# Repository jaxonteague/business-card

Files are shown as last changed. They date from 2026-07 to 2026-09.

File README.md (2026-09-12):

# Business Card - Floppy Bird

<p align="center">
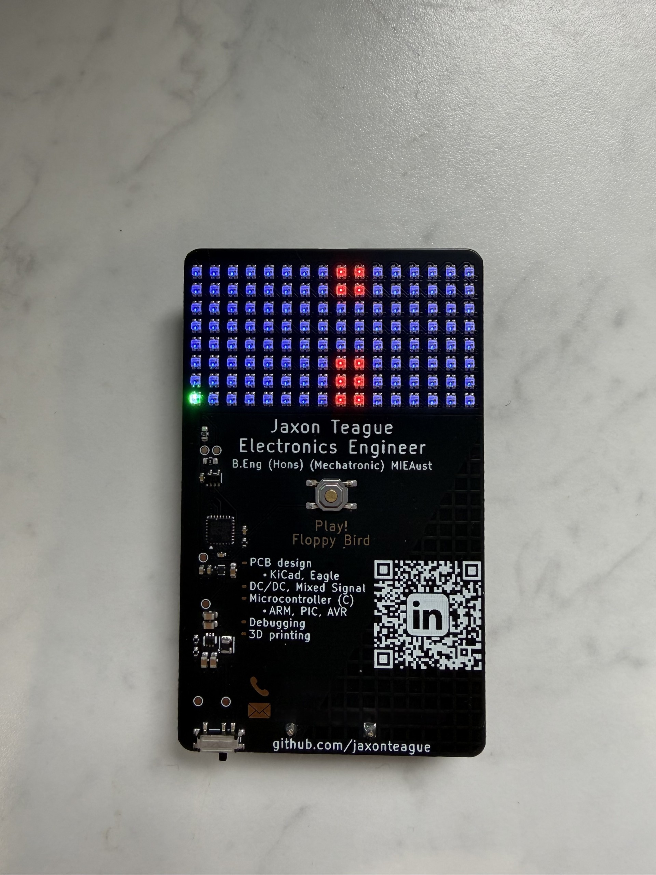
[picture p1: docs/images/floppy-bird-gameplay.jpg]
Floppy Bird running on the LED business card
  
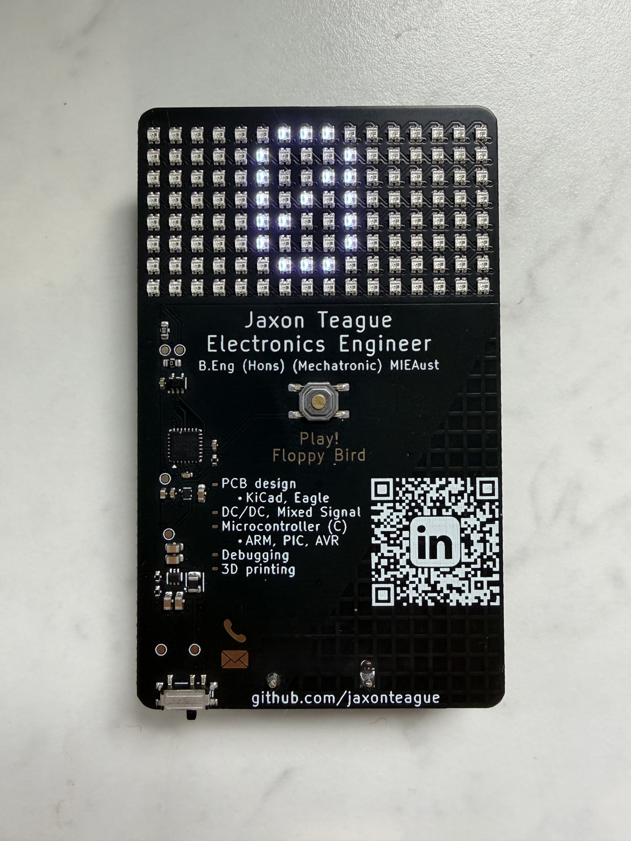
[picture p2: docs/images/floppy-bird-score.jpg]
Score displayed on the LED business card
  
</p>

I wanted my business card to do more than sit in someone's wallet, so I built
one with a custom PCB, 128 RGB LEDs, and a playable game called **Floppy Bird**.
It brings together PCB design, embedded C, real-time game logic, all displayed on
a 16x8 custom led mattrix display.

## What it does

Floppy Bird is controlled with a single physical button. Pressing it makes the
bird flap while two-pixel-wide pipes move across the display. Passing a pipe
earns a point, and the game gradually speeds up across ten difficulty levels.

The player gets three lives. Once all three lives are gone, the final score
appears.

## What I built

- A custom KiCad schematic and PCB for an STM32C031 and 8x16 addressable RGB
  LED matrix.
- A framebuffer-based LED driver that converts RGB values into WS2812 data and
  sends each frame using SPI with DMA.
- Non-blocking game logic covering bird physics, random pipe gaps, collisions,
  lives, scoring, difficulty progression, and game-over handling.
- Interrupt-driven button input with the actual game update kept in the main
  loop, keeping the interrupt handler short.
- Low-power idle time using the Cortex-M0+ wait-for-interrupt instruction.
- Production files including Gerbers, a bill of materials, and component
  placement data.

## Hardware

At the centre of the card is an STM32C031, a small Cortex-M0+ microcontroller
that handles the game, button input, and LED data. The display is made from 128
individually addressable RGB LEDs arranged as 16 columns by 8 rows. A single
physical button provides the game input, keeping the interface simple and making
the card immediately playable.

The card is powered by two AAA batteries. A boost converter raises the battery
voltage to 5 V for the LED matrix, while an LDO steps that rail down to 3.3 V for
the microcontroller. Because the STM32 and LEDs operate at different logic
levels, a level converter shifts the 3.3 V SPI data signal up to 5 V before it
reaches the LEDs. The button input is debounced in hardware with an RC filter so
a single press produces a clean, reliable transition.

The LEDs share one serial data chain and are updated from an SPI peripheral using
DMA. This lets the microcontroller transfer a complete frame in the background
instead of spending all of its time manually generating the LED waveform.

Power consumption was an important part of the design because 128 RGB LEDs can
draw a lot of current at full output. The firmware keeps brightness deliberately
low, and the hardware includes local decoupling for the LED supply.

While the led matrix is cool, it is quite power hungry. Drawing 3/4W, the display
will run for 4-6 hours from 2x AAA batteries.

PCB is 2 layer double sided. The matrix is connected in alternate directions so
as to simpliy routing and avoid unnecessary trace lengths.

## A few interesting details

The LEDs are routed in a serpentine pattern on the PCB. The driver translates
normal `(x, y)` coordinates into the physical LED order, so the game code does
not need to know how the traces are laid out.

The bird uses fixed-point physics instead of floating point. This makes its
movement smoother than jumping directly between the eight rows while staying
lightweight for the Cortex-M0+ microcontroller. Fractional accumulators give
fine control over gravity and pipe speed without floating-point overhead.

The firmware is split into small modules: game logic and rendering are separate
from the LED driver, and adjustable gameplay values live in one configuration
header.

The leds are very bright, so to same battery and eyesight, they are set to very
low brightness.

## Tools and technologies

- Embedded C
- STM32C031 microcontroller
- STM32CubeMX and STM32CubeIDE
- GPIO interrupts, SPI, DMA, and low-power operation
- WS2812-compatible RGB LEDs
- Fixed-point arithmetic and real-time state machines
- KiCad schematic capture and PCB layout
- Design-for-manufacture files for JLCPCB

## Repository contents

The `pcb` folder contains the KiCad design and manufacturing files. The STM32
firmware is in `microcontroller/business card`.

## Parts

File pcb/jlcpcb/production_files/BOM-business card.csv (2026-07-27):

Comment | Designator | Footprint | LCSC | Quantity
0R | R6 | R_0603_1608Metric | C21189 | 1
100 | R1 | R_0603_1608Metric | C22775 | 1
100k | R4,R5 | R_0402_1005Metric | C25741 | 2
100nF | C10,C100,C101,C102,C103,C104,C105,C106,C107,C108,C109,C11,C110,C111,C112,C113,C114,C115,C116,C117,C118,C119,C12,C120,C121,C122,C123,C124,C125,C126,C127,C128,C129,C13,C130,C131,C132,C133,C134,C135,C136,C137,C138,C14,C15,C16,C17,C18,C19,C20,C21,C22,C23,C24,C25,C26,C27,C28,C29,C30,C31,C32,C33,C34,C35,C36,C37,C38,C39,C40,C41,C42,C43,C44,C45,C46,C47,C48,C49,C50,C51,C52,C53,C54,C55,C56,C57,C58,C59,C6,C60,C61,C62,C63,C64,C65,C66,C67,C68,C69,C70,C71,C72,C73,C74,C75,C76,C77,C78,C79,C8,C80,C81,C82,C83,C84,C85,C86,C87,C88,C89,C9,C90,C91,C92,C93,C94,C95,C96,C97,C98,C99 | C_0402_1005Metric | C1525 | 132
10uF | C7 | C_0402_1005Metric | C15525 | 1
10uF | C1,C2,C3,C4 | C_0603_1608Metric | C96446 | 4
2.2uF | C5 | C_0603_1608Metric | C23630 | 1
470nH | L1 | L_Coilcraft_0805HQ_2012Metric | C337914 | 1
732k | R3 | R_0402_1005Metric | C409928 | 1
74AHCT1G125 | U4 | SOT-353_SC-70-5 | C7039245 | 1
Battery | BT1 | BatteryHolder_Keystone_2468_2xAAA | C254917 | 1
STM32C031G6Ux | U1 | QFN-28_4x4mm_P0.5mm | C7324966 | 1
SW_SPDT | SW1 | SW_SPDT_PCM12 | C221841 | 1
TLV71333PDBV | U3 | Texas_X2SON-4_1x1mm_P0.65mm | C90840 | 1
TPS61023DRLR | U2 | DRL0006A | C919459 | 1
Tactile Button, 160gf | S1 | SW-SMD_4P-L5.1-W5.1-P3.70-LS6.5-TL-2 | C318884 | 1
WS2812B | D1,D10,D100,D101,D102,D103,D104,D105,D106,D107,D108,D109,D11,D110,D111,D112,D113,D114,D115,D116,D117,D118,D119,D12,D120,D121,D122,D123,D124,D125,D126,D127,D128,D13,D14,D15,D16,D17,D18,D19,D2,D20,D21,D22,D23,D24,D25,D26,D27,D28,D29,D3,D30,D31,D32,D33,D34,D35,D36,D37,D38,D39,D4,D40,D41,D42,D43,D44,D45,D46,D47,D48,D49,D5,D50,D51,D52,D53,D54,D55,D56,D57,D58,D59,D6,D60,D61,D62,D63,D64,D65,D66,D67,D68,D69,D7,D70,D71,D72,D73,D74,D75,D76,D77,D78,D79,D8,D80,D81,D82,D83,D84,D85,D86,D87,D88,D89,D9,D90,D91,D92,D93,D94,D95,D96,D97,D98,D99 | LED-SMD_4P-L1.6-W1.5_XL-1615RGBC-WS2812B | C5349954 | 128
TestPoint_Probe | TP5 | TestPoint_Pad_D1.0mm |  | 1
TestPoint_Probe | TP2 | TestPoint_Pad_D1.0mm |  | 1
TestPoint_Probe | TP1 | TestPoint_Pad_D1.0mm |  | 1
TestPoint_Probe | TP3 | TestPoint_Pad_D1.0mm |  | 1
TestPoint_Probe | TP4 | TestPoint_Pad_D1.0mm |  | 1
TestPoint_Probe | TP6 | TestPoint_Pad_D1.0mm |  | 1
Conn_ST_STDC14 | J1 | PinHeader_2x07_P1.27mm_Vertical_SMD |  | 1

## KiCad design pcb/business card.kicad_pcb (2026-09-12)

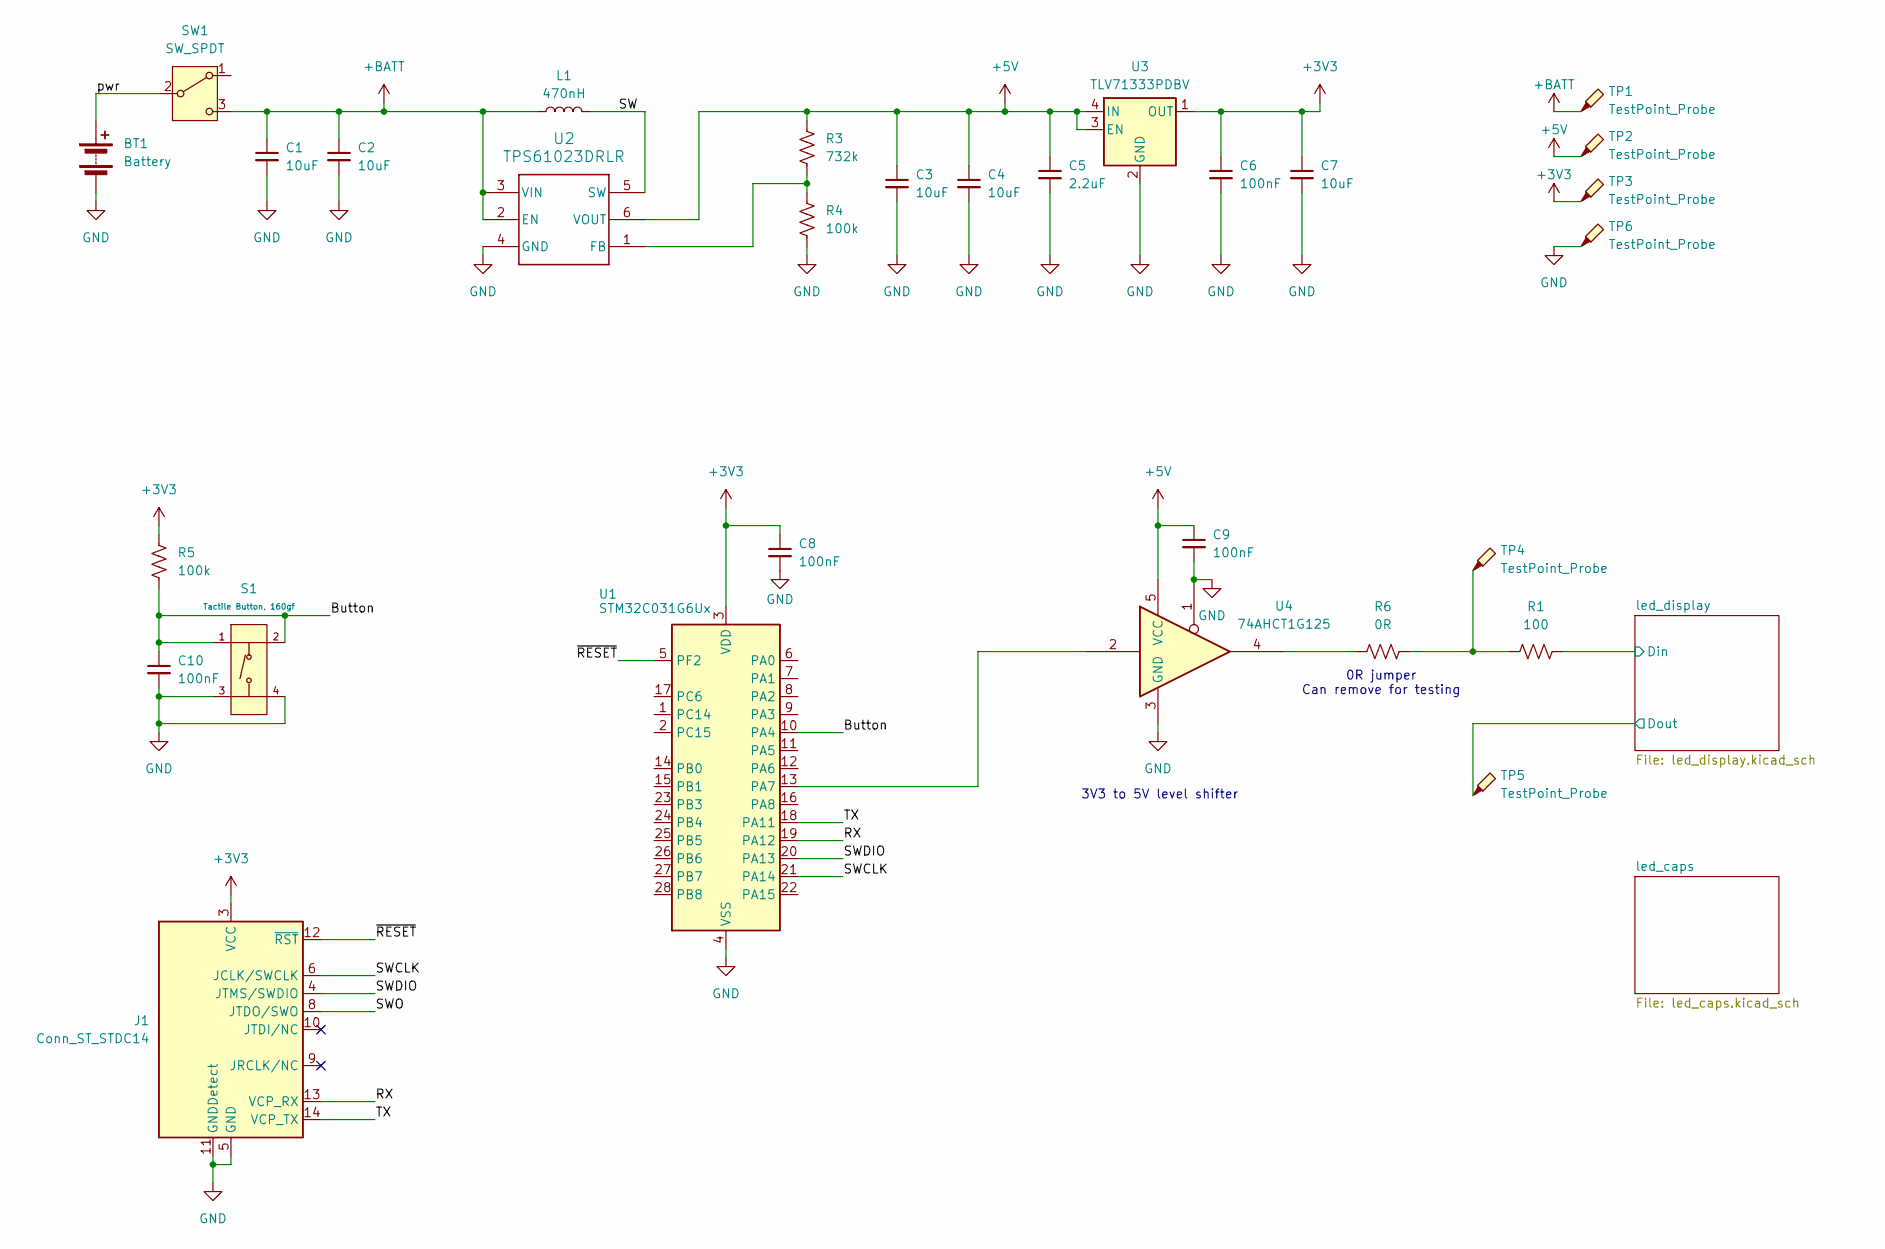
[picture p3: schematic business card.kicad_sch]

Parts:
BT1: Battery; BatteryHolder_Keystone_2468_2xAAA; LCSC C254917
C1, C2, C3, C4: 10uF; C_0603_1608Metric; LCSC C96446
C5: 2.2uF; C_0603_1608Metric; LCSC C23630
C6, C8, C9, C10: 100nF; C_0402_1005Metric; LCSC C1525
C7: 10uF; C_0402_1005Metric; LCSC C15525
J1: Conn_ST_STDC14; PinHeader_2x07_P1.27mm_Vertical_SMD; LCSC C41397116
L1: 470nH; L_Coilcraft_0805HQ_2012Metric; LCSC C337914
R1: 100; R_0603_1608Metric; LCSC C22775
R3: 732k; R_0402_1005Metric; LCSC C409928
R4, R5: 100k; R_0402_1005Metric; LCSC C25741
R6: 0R; R_0603_1608Metric; LCSC C21189
S1: Tactile Button, 160gf; SW-SMD_4P-L5.1-W5.1-P3.70-LS6.5-TL-2; Voltage Rating (Dc) 12V; Part TS-1187A-B-A-B; LCSC C318884
SW1: SW_SPDT; SW_SPDT_PCM12; LCSC C221841
TP1, TP2, TP3, TP4, TP5, TP6: TestPoint_Probe; TestPoint_Pad_D1.0mm
U1: STM32C031G6Ux; QFN-28_4x4mm_P0.5mm; LCSC C7324966
U2: TPS61023DRLR; DRL0006A; LCSC C919459
U3: TLV71333PDBV; Texas_X2SON-4_1x1mm_P0.65mm; LCSC C2867340
U4: 74AHCT1G125; SOT-353_SC-70-5; LCSC C7039245

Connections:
+3V3: C6.1, C7.1, C8.1, J1.3 (VCC), R5.1, TP3.1 (1_1), U1.3 (VDD), U3.1 (OUT)
+5V: C3.1, C4.1, C5.1, C9.1, R3.1, TP2.1 (1_1), U2.6 (VOUT), U3.3 (EN), U3.4 (IN), U4.5 (VCC); also elsewhere on the board
+BATT: C1.1, C2.1, L1.1, SW1.3 (C), TP1.1 (1_1), U2.2 (EN), U2.3 (VIN)
/Button: C10.1, R5.2, S1.1 (A), S1.2 (B), U1.10 (PA4)
/RX: J1.13 (VCP_RX), U1.19 (PA12)
/SW: L1.2, U2.5 (SW)
/SWCLK: J1.6 (JCLK/SWCLK), U1.21 (PA14)
/SWDIO: J1.4 (JTMS/SWDIO), U1.20 (PA13)
/SWO: J1.8 (JTDO/SWO)
/TX: J1.14 (VCP_TX), U1.18 (PA11)
/led_display/Din: R1.2; also elsewhere on the board
/led_display/Dout: TP5.1 (1_1); also elsewhere on the board
/pwr: BT1.1 (+), SW1.2 (B)
/~RESET: J1.12 (~RST), U1.5 (PF2)
GND: BT1.2 (-), C1.2, C2.2, C3.2, C4.2, C5.2, C6.2, C7.2, C8.2, C9.2, C10.2, J1.5 (GND), J1.7 (GND), J1.11 (GNDDetect), R4.2, S1.3 (C), S1.4 (D), TP6.1 (1_1), U1.4 (VSS), U2.4 (GND), U3.2 (GND), U4.1, U4.3 (GND); also elsewhere on the board
unnamed: R1.1, R6.2, TP4.1 (1_1)
unnamed: R6.1, U4.4
unnamed: U1.13 (PA7), U4.2
unnamed: R3.2, R4.1, U2.1 (FB)

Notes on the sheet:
0R jumper Can remove for testing
3V3 to 5V level shifter

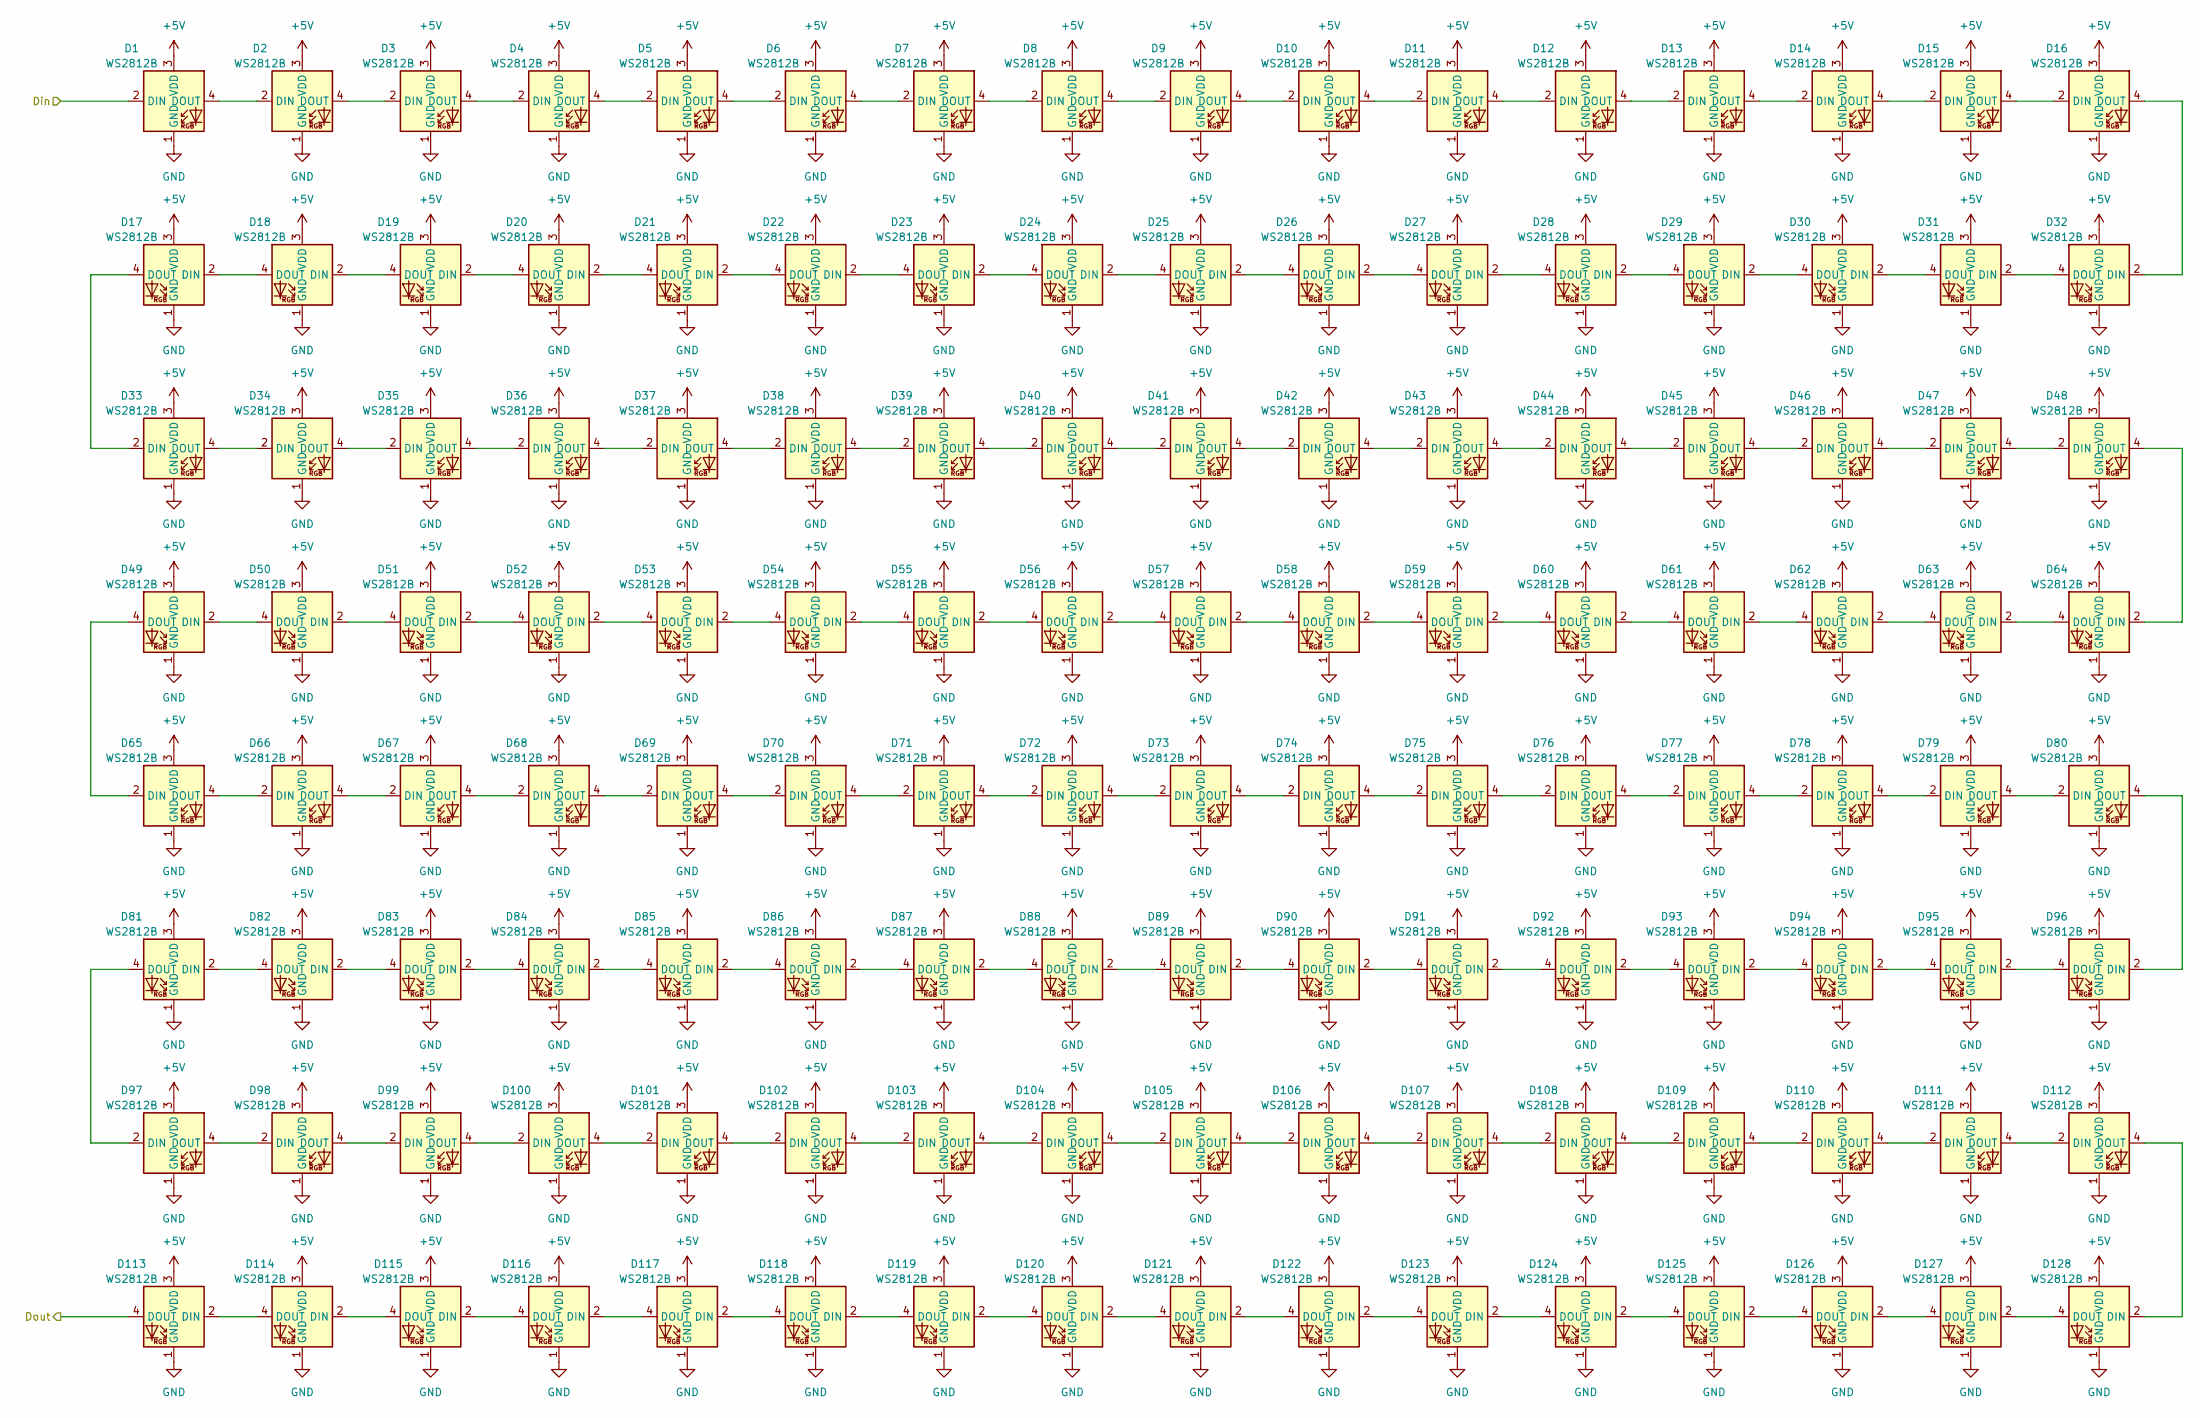
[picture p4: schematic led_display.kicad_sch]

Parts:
D1, D2, D3, D4, D5, D6, D7, D8, D9, D10, D11, D12, D13, D14, D15, D16, D17, D18, D19, D20, D21, D22, D23, D24, D25, D26, D27, D28, D29, D30, D31, D32, D33, D34, D35, D36, D37, D38, D39, D40, D41, D42, D43, D44, D45, D46, D47, D48, D49, D50, D51, D52, D53, D54, D55, D56, D57, D58, D59, D60, D61, D62, D63, D64, D65, D66, D67, D68, D69, D70, D71, D72, D73, D74, D75, D76, D77, D78, D79, D80, D81, D82, D83, D84, D85, D86, D87, D88, D89, D90, D91, D92, D93, D94, D95, D96, D97, D98, D99, D100, D101, D102, D103, D104, D105, D106, D107, D108, D109, D110, D111, D112, D113, D114, D115, D116, D117, D118, D119, D120, D121, D122, D123, D124, D125, D126, D127, D128: WS2812B; LED-SMD_4P-L1.6-W1.5_XL-1615RGBC-WS2812B; LCSC C5349954

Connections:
+5V: D1.3 (VDD), D2.3 (VDD), D3.3 (VDD), D4.3 (VDD), D5.3 (VDD), D6.3 (VDD), D7.3 (VDD), D8.3 (VDD), D9.3 (VDD), D10.3 (VDD), D11.3 (VDD), D12.3 (VDD), D13.3 (VDD), D14.3 (VDD), D15.3 (VDD), D16.3 (VDD), D17.3 (VDD), D18.3 (VDD), D19.3 (VDD), D20.3 (VDD), D21.3 (VDD), D22.3 (VDD), D23.3 (VDD), D24.3 (VDD), D25.3 (VDD), D26.3 (VDD), D27.3 (VDD), D28.3 (VDD), D29.3 (VDD), D30.3 (VDD), D31.3 (VDD), D32.3 (VDD), D33.3 (VDD), D34.3 (VDD), D35.3 (VDD), D36.3 (VDD), D37.3 (VDD), D38.3 (VDD), D39.3 (VDD), D40.3 (VDD), D41.3 (VDD), D42.3 (VDD), D43.3 (VDD), D44.3 (VDD), D45.3 (VDD), D46.3 (VDD), D47.3 (VDD), D48.3 (VDD), D49.3 (VDD), D50.3 (VDD), D51.3 (VDD), D52.3 (VDD), D53.3 (VDD), D54.3 (VDD), D55.3 (VDD), D56.3 (VDD), D57.3 (VDD), D58.3 (VDD), D59.3 (VDD), D60.3 (VDD), D61.3 (VDD), D62.3 (VDD), D63.3 (VDD), D64.3 (VDD), D65.3 (VDD), D66.3 (VDD), D67.3 (VDD), D68.3 (VDD), D69.3 (VDD), D70.3 (VDD), D71.3 (VDD), D72.3 (VDD), D73.3 (VDD), D74.3 (VDD), D75.3 (VDD), D76.3 (VDD), D77.3 (VDD), D78.3 (VDD), D79.3 (VDD), D80.3 (VDD), D81.3 (VDD), D82.3 (VDD), D83.3 (VDD), D84.3 (VDD), D85.3 (VDD), D86.3 (VDD), D87.3 (VDD), D88.3 (VDD), D89.3 (VDD), D90.3 (VDD), D91.3 (VDD), D92.3 (VDD), D93.3 (VDD), D94.3 (VDD), D95.3 (VDD), D96.3 (VDD), D97.3 (VDD), D98.3 (VDD), D99.3 (VDD), D100.3 (VDD), D101.3 (VDD), D102.3 (VDD), D103.3 (VDD), D104.3 (VDD), D105.3 (VDD), D106.3 (VDD), D107.3 (VDD), D108.3 (VDD), D109.3 (VDD), D110.3 (VDD), D111.3 (VDD), D112.3 (VDD), D113.3 (VDD), D114.3 (VDD), D115.3 (VDD), D116.3 (VDD), D117.3 (VDD), D118.3 (VDD), D119.3 (VDD), D120.3 (VDD), D121.3 (VDD), D122.3 (VDD), D123.3 (VDD), D124.3 (VDD), D125.3 (VDD), D126.3 (VDD), D127.3 (VDD), D128.3 (VDD); also elsewhere on the board
/led_display/Din: D1.2 (DIN); also elsewhere on the board
/led_display/Dout: D113.4 (DOUT); also elsewhere on the board
GND: D1.1 (GND), D2.1 (GND), D3.1 (GND), D4.1 (GND), D5.1 (GND), D6.1 (GND), D7.1 (GND), D8.1 (GND), D9.1 (GND), D10.1 (GND), D11.1 (GND), D12.1 (GND), D13.1 (GND), D14.1 (GND), D15.1 (GND), D16.1 (GND), D17.1 (GND), D18.1 (GND), D19.1 (GND), D20.1 (GND), D21.1 (GND), D22.1 (GND), D23.1 (GND), D24.1 (GND), D25.1 (GND), D26.1 (GND), D27.1 (GND), D28.1 (GND), D29.1 (GND), D30.1 (GND), D31.1 (GND), D32.1 (GND), D33.1 (GND), D34.1 (GND), D35.1 (GND), D36.1 (GND), D37.1 (GND), D38.1 (GND), D39.1 (GND), D40.1 (GND), D41.1 (GND), D42.1 (GND), D43.1 (GND), D44.1 (GND), D45.1 (GND), D46.1 (GND), D47.1 (GND), D48.1 (GND), D49.1 (GND), D50.1 (GND), D51.1 (GND), D52.1 (GND), D53.1 (GND), D54.1 (GND), D55.1 (GND), D56.1 (GND), D57.1 (GND), D58.1 (GND), D59.1 (GND), D60.1 (GND), D61.1 (GND), D62.1 (GND), D63.1 (GND), D64.1 (GND), D65.1 (GND), D66.1 (GND), D67.1 (GND), D68.1 (GND), D69.1 (GND), D70.1 (GND), D71.1 (GND), D72.1 (GND), D73.1 (GND), D74.1 (GND), D75.1 (GND), D76.1 (GND), D77.1 (GND), D78.1 (GND), D79.1 (GND), D80.1 (GND), D81.1 (GND), D82.1 (GND), D83.1 (GND), D84.1 (GND), D85.1 (GND), D86.1 (GND), D87.1 (GND), D88.1 (GND), D89.1 (GND), D90.1 (GND), D91.1 (GND), D92.1 (GND), D93.1 (GND), D94.1 (GND), D95.1 (GND), D96.1 (GND), D97.1 (GND), D98.1 (GND), D99.1 (GND), D100.1 (GND), D101.1 (GND), D102.1 (GND), D103.1 (GND), D104.1 (GND), D105.1 (GND), D106.1 (GND), D107.1 (GND), D108.1 (GND), D109.1 (GND), D110.1 (GND), D111.1 (GND), D112.1 (GND), D113.1 (GND), D114.1 (GND), D115.1 (GND), D116.1 (GND), D117.1 (GND), D118.1 (GND), D119.1 (GND), D120.1 (GND), D121.1 (GND), D122.1 (GND), D123.1 (GND), D124.1 (GND), D125.1 (GND), D126.1 (GND), D127.1 (GND), D128.1 (GND); also elsewhere on the board
unnamed: D1.4 (DOUT), D2.2 (DIN)
unnamed: D2.4 (DOUT), D3.2 (DIN)
unnamed: D3.4 (DOUT), D4.2 (DIN)
unnamed: D4.4 (DOUT), D5.2 (DIN)
unnamed: D5.4 (DOUT), D6.2 (DIN)
unnamed: D6.4 (DOUT), D7.2 (DIN)
unnamed: D7.4 (DOUT), D8.2 (DIN)
unnamed: D8.4 (DOUT), D9.2 (DIN)
unnamed: D9.4 (DOUT), D10.2 (DIN)
unnamed: D10.4 (DOUT), D11.2 (DIN)
unnamed: D11.4 (DOUT), D12.2 (DIN)
unnamed: D12.4 (DOUT), D13.2 (DIN)
unnamed: D13.4 (DOUT), D14.2 (DIN)
unnamed: D14.4 (DOUT), D15.2 (DIN)
unnamed: D15.4 (DOUT), D16.2 (DIN)
unnamed: D16.4 (DOUT), D32.2 (DIN)
unnamed: D17.2 (DIN), D18.4 (DOUT)
unnamed: D17.4 (DOUT), D33.2 (DIN)
unnamed: D18.2 (DIN), D19.4 (DOUT)
unnamed: D19.2 (DIN), D20.4 (DOUT)
unnamed: D20.2 (DIN), D21.4 (DOUT)
unnamed: D21.2 (DIN), D22.4 (DOUT)
unnamed: D22.2 (DIN), D23.4 (DOUT)
unnamed: D23.2 (DIN), D24.4 (DOUT)
unnamed: D24.2 (DIN), D25.4 (DOUT)
unnamed: D25.2 (DIN), D26.4 (DOUT)
unnamed: D26.2 (DIN), D27.4 (DOUT)
unnamed: D27.2 (DIN), D28.4 (DOUT)
unnamed: D28.2 (DIN), D29.4 (DOUT)
unnamed: D29.2 (DIN), D30.4 (DOUT)
unnamed: D30.2 (DIN), D31.4 (DOUT)
unnamed: D31.2 (DIN), D32.4 (DOUT)
unnamed: D33.4 (DOUT), D34.2 (DIN)
unnamed: D34.4 (DOUT), D35.2 (DIN)
unnamed: D35.4 (DOUT), D36.2 (DIN)
unnamed: D36.4 (DOUT), D37.2 (DIN)
unnamed: D37.4 (DOUT), D38.2 (DIN)
unnamed: D38.4 (DOUT), D39.2 (DIN)
unnamed: D39.4 (DOUT), D40.2 (DIN)
unnamed: D40.4 (DOUT), D41.2 (DIN)
unnamed: D41.4 (DOUT), D42.2 (DIN)
unnamed: D42.4 (DOUT), D43.2 (DIN)
unnamed: D43.4 (DOUT), D44.2 (DIN)
unnamed: D44.4 (DOUT), D45.2 (DIN)
unnamed: D45.4 (DOUT), D46.2 (DIN)
unnamed: D46.4 (DOUT), D47.2 (DIN)
unnamed: D47.4 (DOUT), D48.2 (DIN)
unnamed: D48.4 (DOUT), D64.2 (DIN)
unnamed: D49.2 (DIN), D50.4 (DOUT)
unnamed: D49.4 (DOUT), D65.2 (DIN)
unnamed: D50.2 (DIN), D51.4 (DOUT)
unnamed: D51.2 (DIN), D52.4 (DOUT)
unnamed: D52.2 (DIN), D53.4 (DOUT)
unnamed: D53.2 (DIN), D54.4 (DOUT)
unnamed: D54.2 (DIN), D55.4 (DOUT)
unnamed: D55.2 (DIN), D56.4 (DOUT)
unnamed: D56.2 (DIN), D57.4 (DOUT)
unnamed: D57.2 (DIN), D58.4 (DOUT)
unnamed: D58.2 (DIN), D59.4 (DOUT)
unnamed: D59.2 (DIN), D60.4 (DOUT)
unnamed: D60.2 (DIN), D61.4 (DOUT)
unnamed: D61.2 (DIN), D62.4 (DOUT)
unnamed: D62.2 (DIN), D63.4 (DOUT)
unnamed: D63.2 (DIN), D64.4 (DOUT)
unnamed: D65.4 (DOUT), D66.2 (DIN)
unnamed: D66.4 (DOUT), D67.2 (DIN)
unnamed: D67.4 (DOUT), D68.2 (DIN)
unnamed: D68.4 (DOUT), D69.2 (DIN)
unnamed: D69.4 (DOUT), D70.2 (DIN)
unnamed: D70.4 (DOUT), D71.2 (DIN)
unnamed: D71.4 (DOUT), D72.2 (DIN)
unnamed: D72.4 (DOUT), D73.2 (DIN)
unnamed: D73.4 (DOUT), D74.2 (DIN)
unnamed: D74.4 (DOUT), D75.2 (DIN)
unnamed: D75.4 (DOUT), D76.2 (DIN)
unnamed: D76.4 (DOUT), D77.2 (DIN)
unnamed: D77.4 (DOUT), D78.2 (DIN)
unnamed: D78.4 (DOUT), D79.2 (DIN)
unnamed: D79.4 (DOUT), D80.2 (DIN)
unnamed: D80.4 (DOUT), D96.2 (DIN)
unnamed: D81.2 (DIN), D82.4 (DOUT)
unnamed: D81.4 (DOUT), D97.2 (DIN)
unnamed: D82.2 (DIN), D83.4 (DOUT)
unnamed: D83.2 (DIN), D84.4 (DOUT)
unnamed: D84.2 (DIN), D85.4 (DOUT)
unnamed: D85.2 (DIN), D86.4 (DOUT)
unnamed: D86.2 (DIN), D87.4 (DOUT)
unnamed: D87.2 (DIN), D88.4 (DOUT)
unnamed: D88.2 (DIN), D89.4 (DOUT)
unnamed: D89.2 (DIN), D90.4 (DOUT)
unnamed: D90.2 (DIN), D91.4 (DOUT)
unnamed: D91.2 (DIN), D92.4 (DOUT)
unnamed: D92.2 (DIN), D93.4 (DOUT)
unnamed: D93.2 (DIN), D94.4 (DOUT)
unnamed: D94.2 (DIN), D95.4 (DOUT)
unnamed: D95.2 (DIN), D96.4 (DOUT)
unnamed: D97.4 (DOUT), D98.2 (DIN)
unnamed: D98.4 (DOUT), D99.2 (DIN)
unnamed: D99.4 (DOUT), D100.2 (DIN)
unnamed: D100.4 (DOUT), D101.2 (DIN)
unnamed: D101.4 (DOUT), D102.2 (DIN)
unnamed: D102.4 (DOUT), D103.2 (DIN)
unnamed: D103.4 (DOUT), D104.2 (DIN)
unnamed: D104.4 (DOUT), D105.2 (DIN)
unnamed: D105.4 (DOUT), D106.2 (DIN)
unnamed: D106.4 (DOUT), D107.2 (DIN)
unnamed: D107.4 (DOUT), D108.2 (DIN)
unnamed: D108.4 (DOUT), D109.2 (DIN)
unnamed: D109.4 (DOUT), D110.2 (DIN)
unnamed: D110.4 (DOUT), D111.2 (DIN)
unnamed: D111.4 (DOUT), D112.2 (DIN)
unnamed: D112.4 (DOUT), D128.2 (DIN)
unnamed: D113.2 (DIN), D114.4 (DOUT)
unnamed: D114.2 (DIN), D115.4 (DOUT)
unnamed: D115.2 (DIN), D116.4 (DOUT)
unnamed: D116.2 (DIN), D117.4 (DOUT)
unnamed: D117.2 (DIN), D118.4 (DOUT)
unnamed: D118.2 (DIN), D119.4 (DOUT)
unnamed: D119.2 (DIN), D120.4 (DOUT)
unnamed: D120.2 (DIN), D121.4 (DOUT)
unnamed: D121.2 (DIN), D122.4 (DOUT)
unnamed: D122.2 (DIN), D123.4 (DOUT)
unnamed: D123.2 (DIN), D124.4 (DOUT)
unnamed: D124.2 (DIN), D125.4 (DOUT)
unnamed: D125.2 (DIN), D126.4 (DOUT)
unnamed: D126.2 (DIN), D127.4 (DOUT)
unnamed: D127.2 (DIN), D128.4 (DOUT)

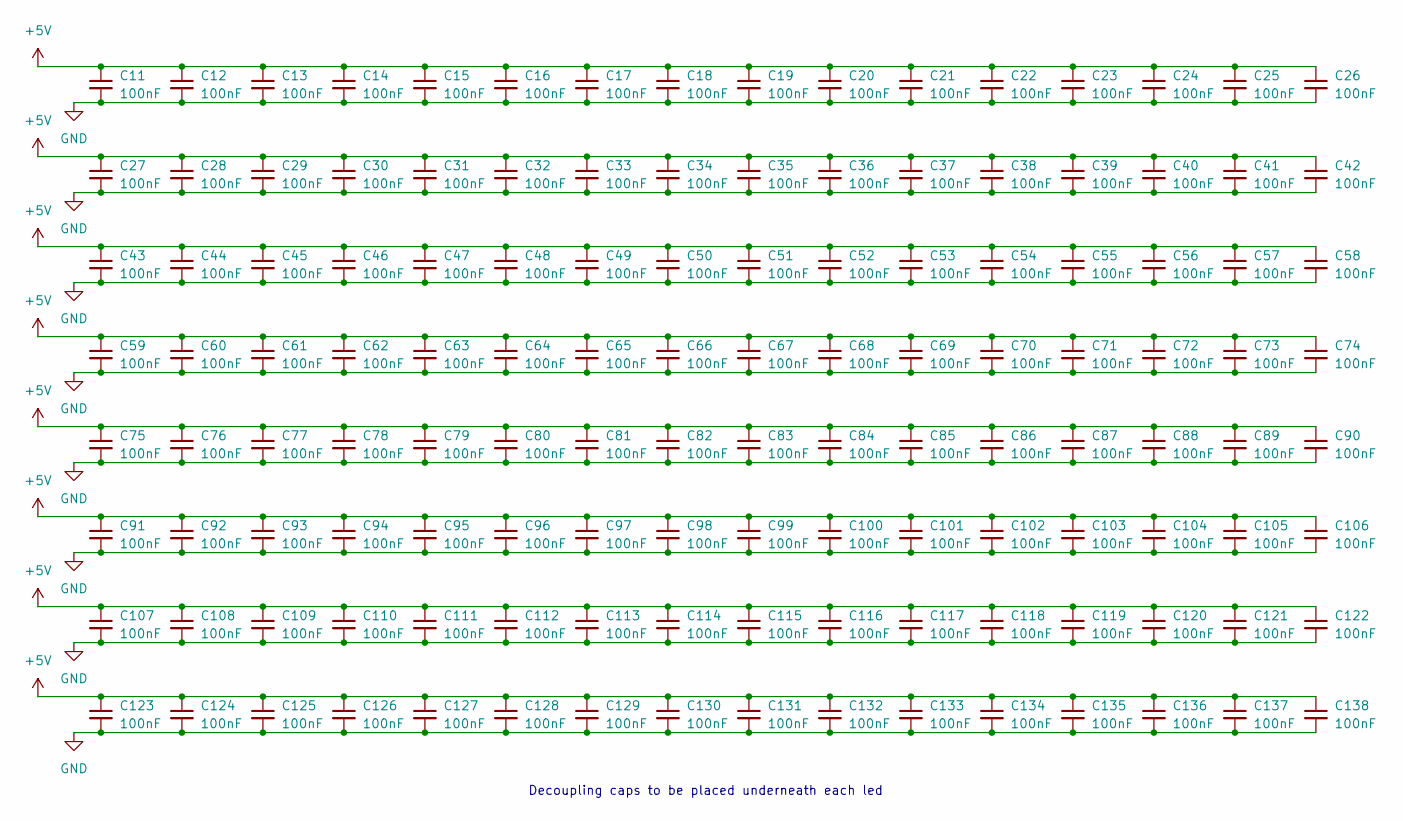
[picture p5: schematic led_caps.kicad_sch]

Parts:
C11, C12, C13, C14, C15, C16, C17, C18, C19, C20, C21, C22, C23, C24, C25, C26, C27, C28, C29, C30, C31, C32, C33, C34, C35, C36, C37, C38, C39, C40, C41, C42, C43, C44, C45, C46, C47, C48, C49, C50, C51, C52, C53, C54, C55, C56, C57, C58, C59, C60, C61, C62, C63, C64, C65, C66, C67, C68, C69, C70, C71, C72, C73, C74, C75, C76, C77, C78, C79, C80, C81, C82, C83, C84, C85, C86, C87, C88, C89, C90, C91, C92, C93, C94, C95, C96, C97, C98, C99, C100, C101, C102, C103, C104, C105, C106, C107, C108, C109, C110, C111, C112, C113, C114, C115, C116, C117, C118, C119, C120, C121, C122, C123, C124, C125, C126, C127, C128, C129, C130, C131, C132, C133, C134, C135, C136, C137, C138: 100nF; C_0402_1005Metric; LCSC C1525

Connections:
+5V: C11.1, C12.1, C13.1, C14.1, C15.1, C16.1, C17.1, C18.1, C19.1, C20.1, C21.1, C22.1, C23.1, C24.1, C25.1, C26.1, C27.1, C28.1, C29.1, C30.1, C31.1, C32.1, C33.1, C34.1, C35.1, C36.1, C37.1, C38.1, C39.1, C40.1, C41.1, C42.1, C43.1, C44.1, C45.1, C46.1, C47.1, C48.1, C49.1, C50.1, C51.1, C52.1, C53.1, C54.1, C55.1, C56.1, C57.1, C58.1, C59.1, C60.1, C61.1, C62.1, C63.1, C64.1, C65.1, C66.1, C67.1, C68.1, C69.1, C70.1, C71.1, C72.1, C73.1, C74.1, C75.1, C76.1, C77.1, C78.1, C79.1, C80.1, C81.1, C82.1, C83.1, C84.1, C85.1, C86.1, C87.1, C88.1, C89.1, C90.1, C91.1, C92.1, C93.1, C94.1, C95.1, C96.1, C97.1, C98.1, C99.1, C100.1, C101.1, C102.1, C103.1, C104.1, C105.1, C106.1, C107.1, C108.1, C109.1, C110.1, C111.1, C112.1, C113.1, C114.1, C115.1, C116.1, C117.1, C118.1, C119.1, C120.1, C121.1, C122.1, C123.1, C124.1, C125.1, C126.1, C127.1, C128.1, C129.1, C130.1, C131.1, C132.1, C133.1, C134.1, C135.1, C136.1, C137.1, C138.1; also elsewhere on the board
GND: C11.2, C12.2, C13.2, C14.2, C15.2, C16.2, C17.2, C18.2, C19.2, C20.2, C21.2, C22.2, C23.2, C24.2, C25.2, C26.2, C27.2, C28.2, C29.2, C30.2, C31.2, C32.2, C33.2, C34.2, C35.2, C36.2, C37.2, C38.2, C39.2, C40.2, C41.2, C42.2, C43.2, C44.2, C45.2, C46.2, C47.2, C48.2, C49.2, C50.2, C51.2, C52.2, C53.2, C54.2, C55.2, C56.2, C57.2, C58.2, C59.2, C60.2, C61.2, C62.2, C63.2, C64.2, C65.2, C66.2, C67.2, C68.2, C69.2, C70.2, C71.2, C72.2, C73.2, C74.2, C75.2, C76.2, C77.2, C78.2, C79.2, C80.2, C81.2, C82.2, C83.2, C84.2, C85.2, C86.2, C87.2, C88.2, C89.2, C90.2, C91.2, C92.2, C93.2, C94.2, C95.2, C96.2, C97.2, C98.2, C99.2, C100.2, C101.2, C102.2, C103.2, C104.2, C105.2, C106.2, C107.2, C108.2, C109.2, C110.2, C111.2, C112.2, C113.2, C114.2, C115.2, C116.2, C117.2, C118.2, C119.2, C120.2, C121.2, C122.2, C123.2, C124.2, C125.2, C126.2, C127.2, C128.2, C129.2, C130.2, C131.2, C132.2, C133.2, C134.2, C135.2, C136.2, C137.2, C138.2; also elsewhere on the board

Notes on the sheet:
Decoupling caps to be placed underneath each led

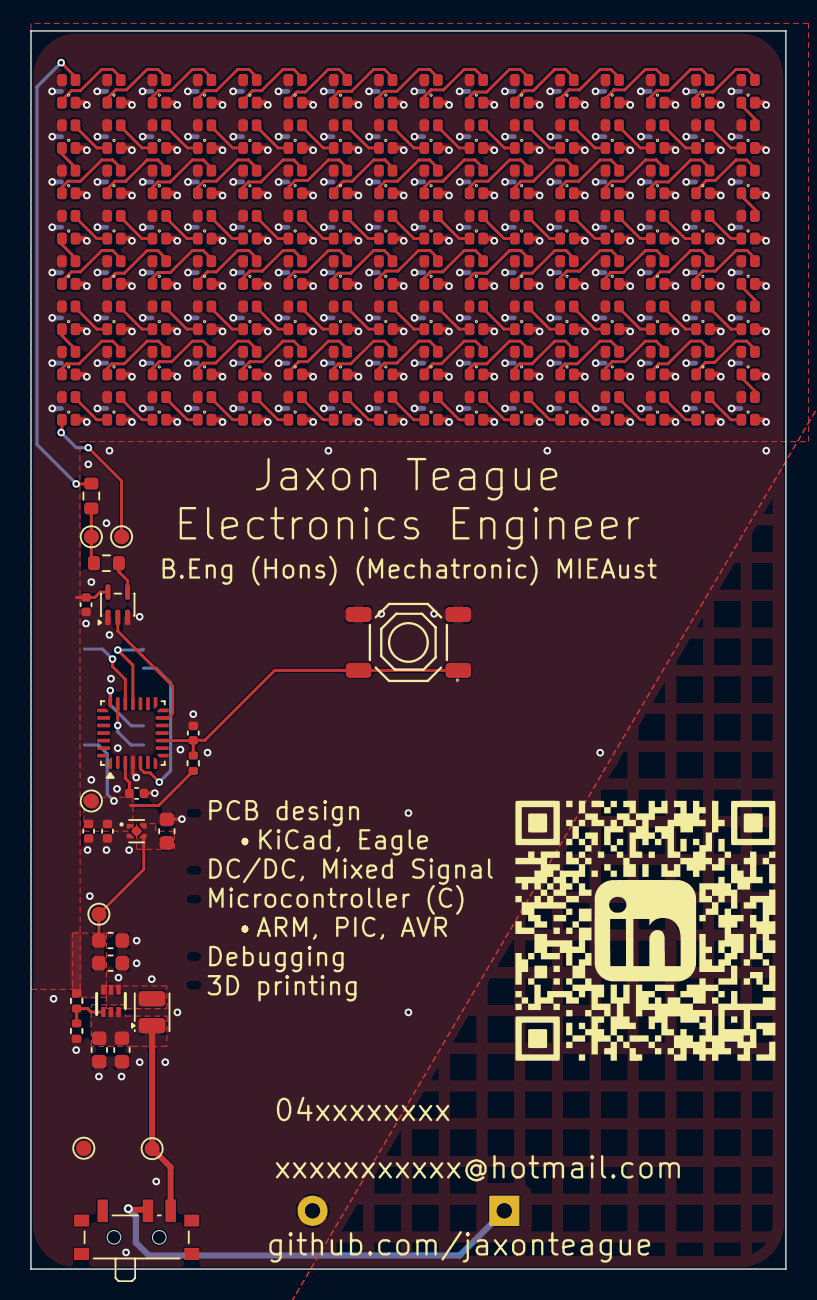
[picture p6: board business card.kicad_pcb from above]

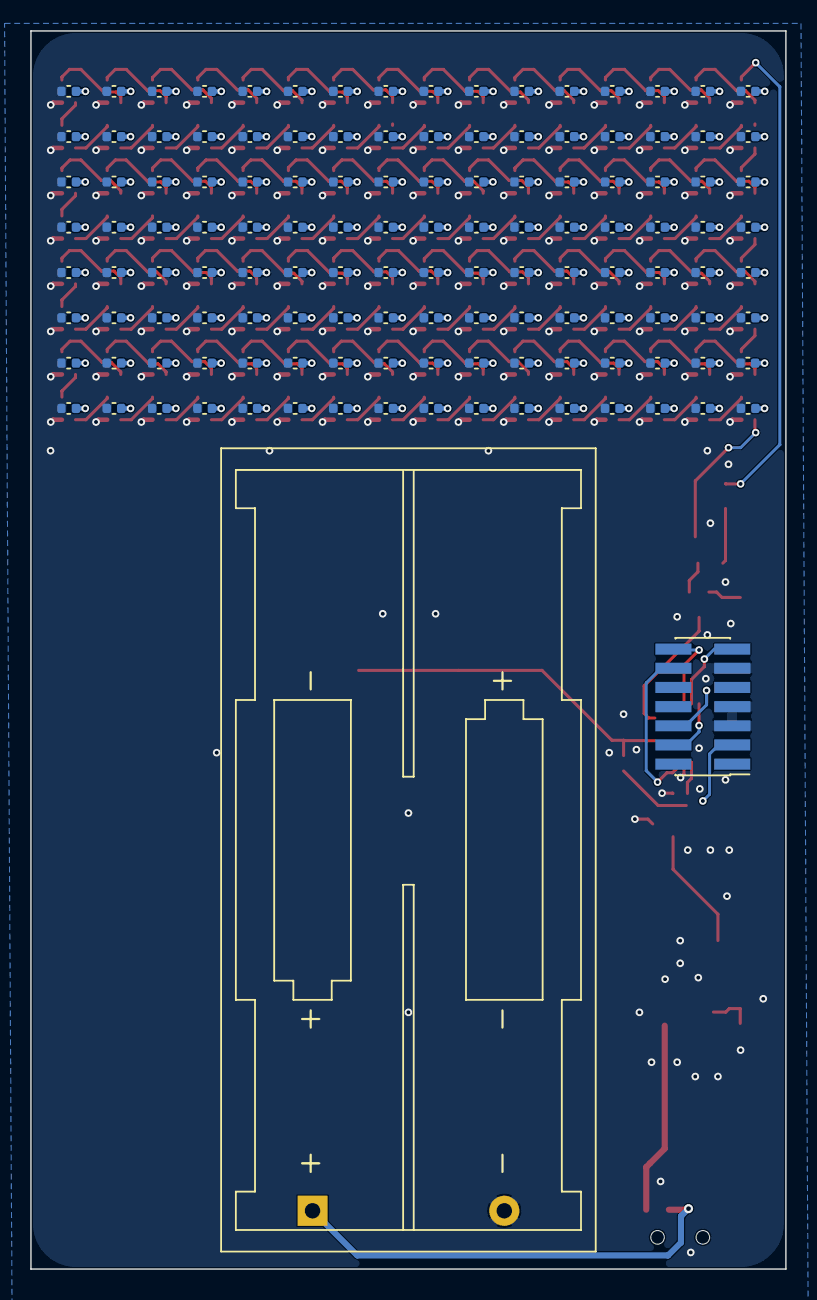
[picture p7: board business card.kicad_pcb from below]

Board: 2 copper layers, 50.0 x 82.0 mm, 286 parts (130 on the bottom side), 145 nets.

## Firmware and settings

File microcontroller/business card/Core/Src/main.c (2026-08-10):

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
/* Includes ------------------------------------------------------------------*/
#include "main.h"
#include "dma.h"
#include "spi.h"
#include "usart.h"
#include "gpio.h"

/* USER CODE BEGIN Includes */
#include "led.h"
#include "game.h"
/* USER CODE END Includes */


void SystemClock_Config(void);
/**
  * @brief  The application entry point.
  * @retval int
  */
int main(void)
{

  /* MCU Configuration--------------------------------------------------------*/

  /* Reset of all peripherals, Initializes the Flash interface and the Systick. */
  HAL_Init();

  /* Configure the system clock */
  SystemClock_Config();

  /* Initialize all configured peripherals */
  MX_GPIO_Init();
  MX_DMA_Init();
  MX_SPI1_Init();
  MX_USART1_UART_Init();
  /* USER CODE BEGIN 2 */

  LED_Init();
  Game_Init();

  /* USER CODE END 2 */

  /* Infinite loop */
  /* USER CODE BEGIN WHILE */
  while (1)
  {

	  Game_Task();
	  __WFI();


    /* USER CODE END WHILE */

    /* USER CODE BEGIN 3 */
  }
  /* USER CODE END 3 */
}

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
/* USER CODE BEGIN 4 */

/**
  * @brief Forward falling-edge button interrupts to the game input queue.
  * @param GPIO_Pin Pin mask supplied by the HAL EXTI dispatcher.
  */
void HAL_GPIO_EXTI_Falling_Callback(uint16_t GPIO_Pin)
{
  /* Ignore unrelated EXTI sources that may share the callback. */
  if (GPIO_Pin == Button_Pin)
  {
    Game_ButtonPressed();
  }
}

/* USER CODE END 4 */
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


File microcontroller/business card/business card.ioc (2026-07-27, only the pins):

Mcu.UserName=STM32C031G6Ux
PA1.Signal=SPI1_SCK
PA13.Signal=DEBUG_SWDIO
PA14-BOOT0.Signal=DEBUG_SWCLK
PA4.GPIO_Label=Button
PA4.Signal=GPXTI4
PA7.GPIO_Label=Led_Data
PA7.Signal=SPI1_MOSI

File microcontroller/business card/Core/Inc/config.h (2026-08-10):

/**
 * @file config.h
 * @brief Compile-time settings for game timing, physics, and appearance.
 *
 * Created on: 26 July 2026
 * Author: Jaxon Teague
 */

#ifndef INC_CONFIG_H_
#define INC_CONFIG_H_


/* Frame period in milliseconds; 16 ms produces approximately 60 FPS. */
#define GAME_UPDATE_PERIOD_MS    16U


/* Bird start coordinates and RGB brightness values. */
#define PLAYER_START_X                 0U
#define PLAYER_START_Y                 3U
#define BIRD_RED                       0U
#define BIRD_GREEN                     255U
#define BIRD_BLUE                      0U
#define BIRD_BRIGHTNESS                20U

/* Physics uses 1/16-pixel units; negative is up and positive is down. */
#define BIRD_FLAP_VELOCITY             (-7)
#define BIRD_GRAVITY                   1
#define BIRD_GRAVITY_NUMERATOR         3U
#define BIRD_GRAVITY_DENOMINATOR       4U
#define BIRD_TERMINAL_VELOCITY         6

/* Player lives and collision/game-over timing. */
#define PLAYER_STARTING_LIVES          3U
#define PIPE_HIT_FLASH_MS              600U
#define PIPE_HIT_FLASH_PERIOD_MS       100U
#define GAME_OVER_SCORE_DELAY_MS       3000U

/* Bird colours change with the number of remaining lives. */
#define BIRD_TWO_LIVES_RED             255U
#define BIRD_TWO_LIVES_GREEN           255U
#define BIRD_TWO_LIVES_BLUE            255U
#define BIRD_ONE_LIFE_RED              255U
#define BIRD_ONE_LIFE_GREEN            255U
#define BIRD_ONE_LIFE_BLUE             0U

/* Pipe geometry and movement rate. */
#define PIPE_WIDTH                     2U
#define PIPE_GAP_HEIGHT                3U
#define PIPE_MOVE_RATE_SCALE           40U
#define PIPE_MOVE_RATE_START           5U
#define PIPE_MOVE_RATE_PER_LEVEL       1U
#define PIPE_SPEEDUP_SCORE_INTERVAL    5U
#define PIPE_DIFFICULTY_LEVEL_COUNT    10U
#define PIPE_MAX_DIFFICULTY_LEVEL      (PIPE_DIFFICULTY_LEVEL_COUNT - 1U)
#define PIPE_RED                       255U
#define PIPE_GREEN                     0U
#define PIPE_BLUE                      0U
#define PIPE_BRIGHTNESS                6U
#define PIPE_HIT_BRIGHTNESS            12U

/* Fixed background palette entries use the minimum non-zero brightness. */
#define BACKGROUND_BLUE_RED            0U
#define BACKGROUND_BLUE_GREEN          0U
#define BACKGROUND_BLUE_BLUE           255U
#define BACKGROUND_PURPLE_RED          255U
#define BACKGROUND_PURPLE_GREEN        0U
#define BACKGROUND_PURPLE_BLUE         255U
#define BACKGROUND_BRIGHTNESS          1U

/* Large game-over score appearance. */
#define DIGIT_RED                      255U
#define DIGIT_GREEN                    255U
#define DIGIT_BLUE                     255U
#define DIGIT_BRIGHTNESS               4U

#endif /* INC_CONFIG_H_ */

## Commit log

2026-07-29 fixed leds bug where buffer was being written to mid transmission causing most of the leds to not work. Added demo led code
    [config.h, game.c, led.c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]
2026-07-29 Add button-controlled bird animation
2026-09-12 Organize PCB project files
    [BOM-business card.csv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]
2026-09-12 Update PCB design and project overview
    [business card.kicad_pcb]

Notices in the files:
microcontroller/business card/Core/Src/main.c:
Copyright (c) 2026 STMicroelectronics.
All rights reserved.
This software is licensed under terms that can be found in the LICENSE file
